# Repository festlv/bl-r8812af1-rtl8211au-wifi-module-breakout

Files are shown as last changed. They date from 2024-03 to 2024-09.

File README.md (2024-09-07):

# BL-R8812AF1 (RTL8211AU) module breakout

Features:
* 5..18V power input
* JST GH for USB/power
* 12pin FFC connector (pinout for IVG-G3S / GK7205V210+IMX307) camera module- USB, microSD slot (optionally: power)

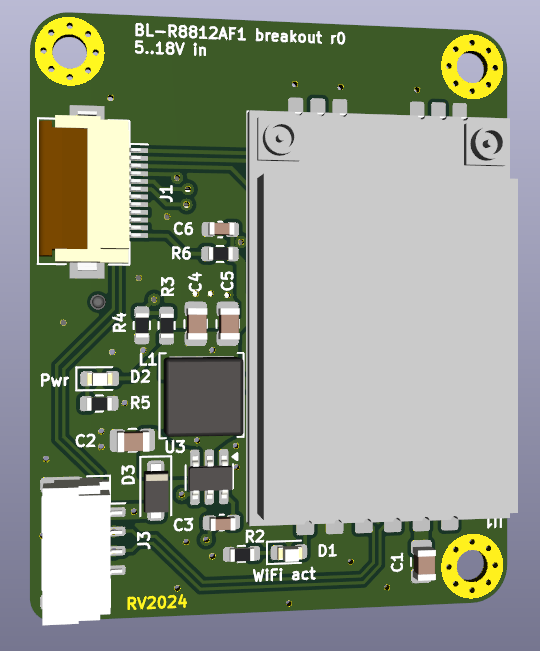
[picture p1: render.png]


Current state:
* Power input tested and working fine at 5 and 12V
* WiFi module works
* FFC connection untested

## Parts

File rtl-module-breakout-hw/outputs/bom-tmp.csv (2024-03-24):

Item | Qty | Reference(s) | Value | LibPart | Footprint | Datasheet | DNP | AltMPN | AltManufacturer | Config | LCSC# | MPN | Manufacturer
1 | 3 | C1, C4, C5 | 22uF | Device:C_Small | Capacitor_SMD:C_0805_2012Metric | ~ |  |  |  |  | C380338
2 | 1 | C2 | 10uF | Device:C_Small | Capacitor_SMD:C_0805_2012Metric | ~ |  |  |  |  | C15850
3 | 2 | C3, C6 | 0.1uF | Device:C_Small | Capacitor_SMD:C_0603_1608Metric | ~
4 | 1 | D1 | LED_GREEN | hadv-ui:LED_GREEN | LED_SMD:LED_0603_1608Metric | ~ |  |  |  |  | C434423 | SZYY0603YG | Yongyu Photoelectric
5 | 1 | D2 | LED_RED | hadv-ui:LED_RED | LED_SMD:LED_0603_1608Metric | ~ |  |  |  |  | C434419 | SZYY0603R | Yongyu Photoelectric
6 | 1 | D3 | DSS34 | hadv-diodes:DSS34 | Diode_SMD:D_SOD-123F | https://datasheet.lcsc.com/lcsc/2004141809_BORN-DSS34_C511866.pdf |  |  |  |  | C511866 | DSS34 | BORN
7 | 1 | J1 | FFC_12p_H | hadv-connectors:FFC_12p_H | Connector_FFC-FPC:Hirose_FH12-12S-0.5SH_1x12-1MP_P0.50mm_Horizontal | ~ |  |  |  |  | C262290 | AFC24-S12FIC-00 | JUSHUO
8 | 1 | J2 | TF-01A | hadv-connectors:TF-01A | hadv-connectors:TF-01A | https://datasheet.lcsc.com/lcsc/1811082127_Korean-Hroparts-Elec-TF-01A_C91145.pdf |  |  |  |  | C91145 | TF-01A | Korean Hroparts
9 | 1 | J3 | JST-GH-4H | hadv-connectors:JST-GH-4H | Connector_JST:JST_GH_SM04B-GHS-TB_1x04-1MP_P1.25mm_Horizontal | ~ |  | X1251WRS-04HF-LPSW | XKB |  | C388709 | SM04B-GHS-TB | JST
10 | 1 | L1 | LQH5BPN3R3N38L | hadv-inductors:LQH5BPN3R3N38L | Inductor_SMD:L_Sunlord_SWPA5020S | ~ |  |  |  |  | C703751 | LQH5BPN3R3N38L | Murata
11 | 2 | R1, R4 | 10K | Device:R_Small | Resistor_SMD:R_0603_1608Metric | ~
12 | 2 | R2, R5 | 220R | Device:R_Small | Resistor_SMD:R_0603_1608Metric | ~ |  |  |  |  | C22962
13 | 1 | R3 | 31K6 | Device:R_Small | Resistor_SMD:R_0603_1608Metric | ~ |  |  |  |  | C25967 | 0603WAF3162T5E
14 | 1 | R6 | 0R | Device:R_Small | Resistor_SMD:R_0603_1608Metric | ~ | DNP |  |  | DNP
15 | 1 | U1 | ~ | hadv-rf:BL-R8812AF1 | hadv-rf:BL-R8812AF1 |  |  |  |  |  |  | BL-R8812AF1 | Unknown
16 | 1 | U3 | AP62300WU | hadv-vregs:AP62300WU | Package_TO_SOT_SMD:TSOT-23-6 | https://www.diodes.com/assets/Datasheets/AP62300_AP62301_AP62300T.pdf |  |  |  |  | C1880390 | AP62300WU-7 | Diodes Inc

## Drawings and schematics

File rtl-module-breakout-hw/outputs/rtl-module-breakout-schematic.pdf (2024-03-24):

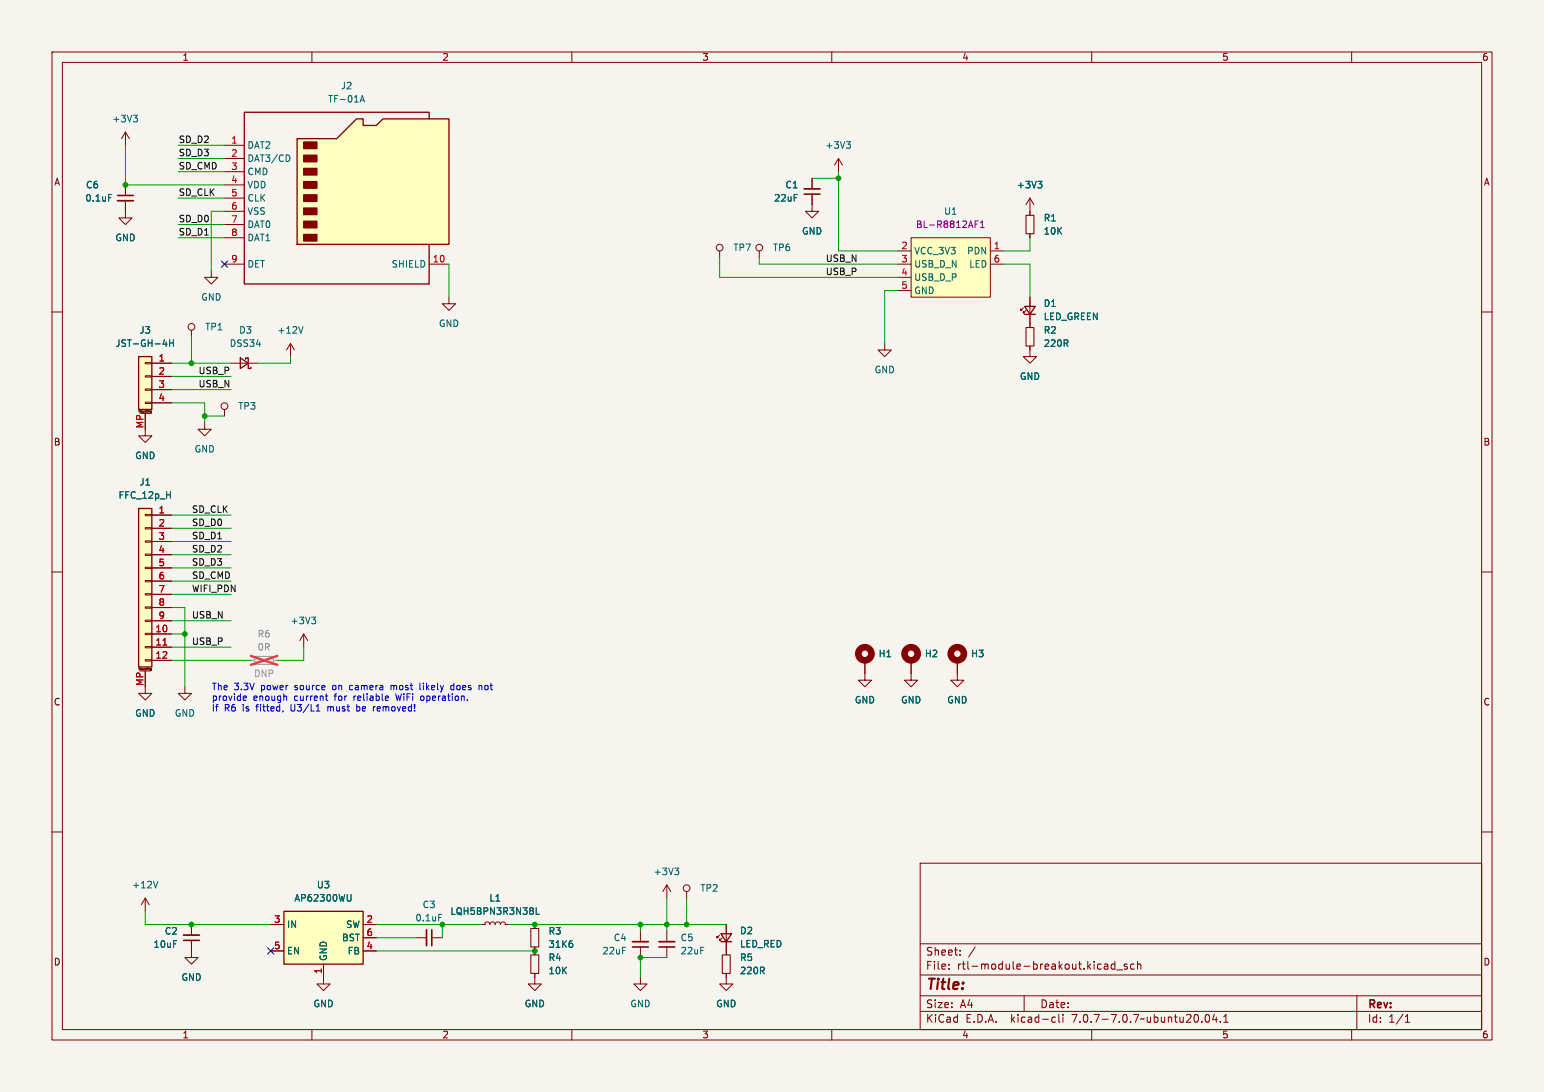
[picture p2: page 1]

Id: 1/1 Title: File: rtl-module-breakout.kicad_sch Sheet: /

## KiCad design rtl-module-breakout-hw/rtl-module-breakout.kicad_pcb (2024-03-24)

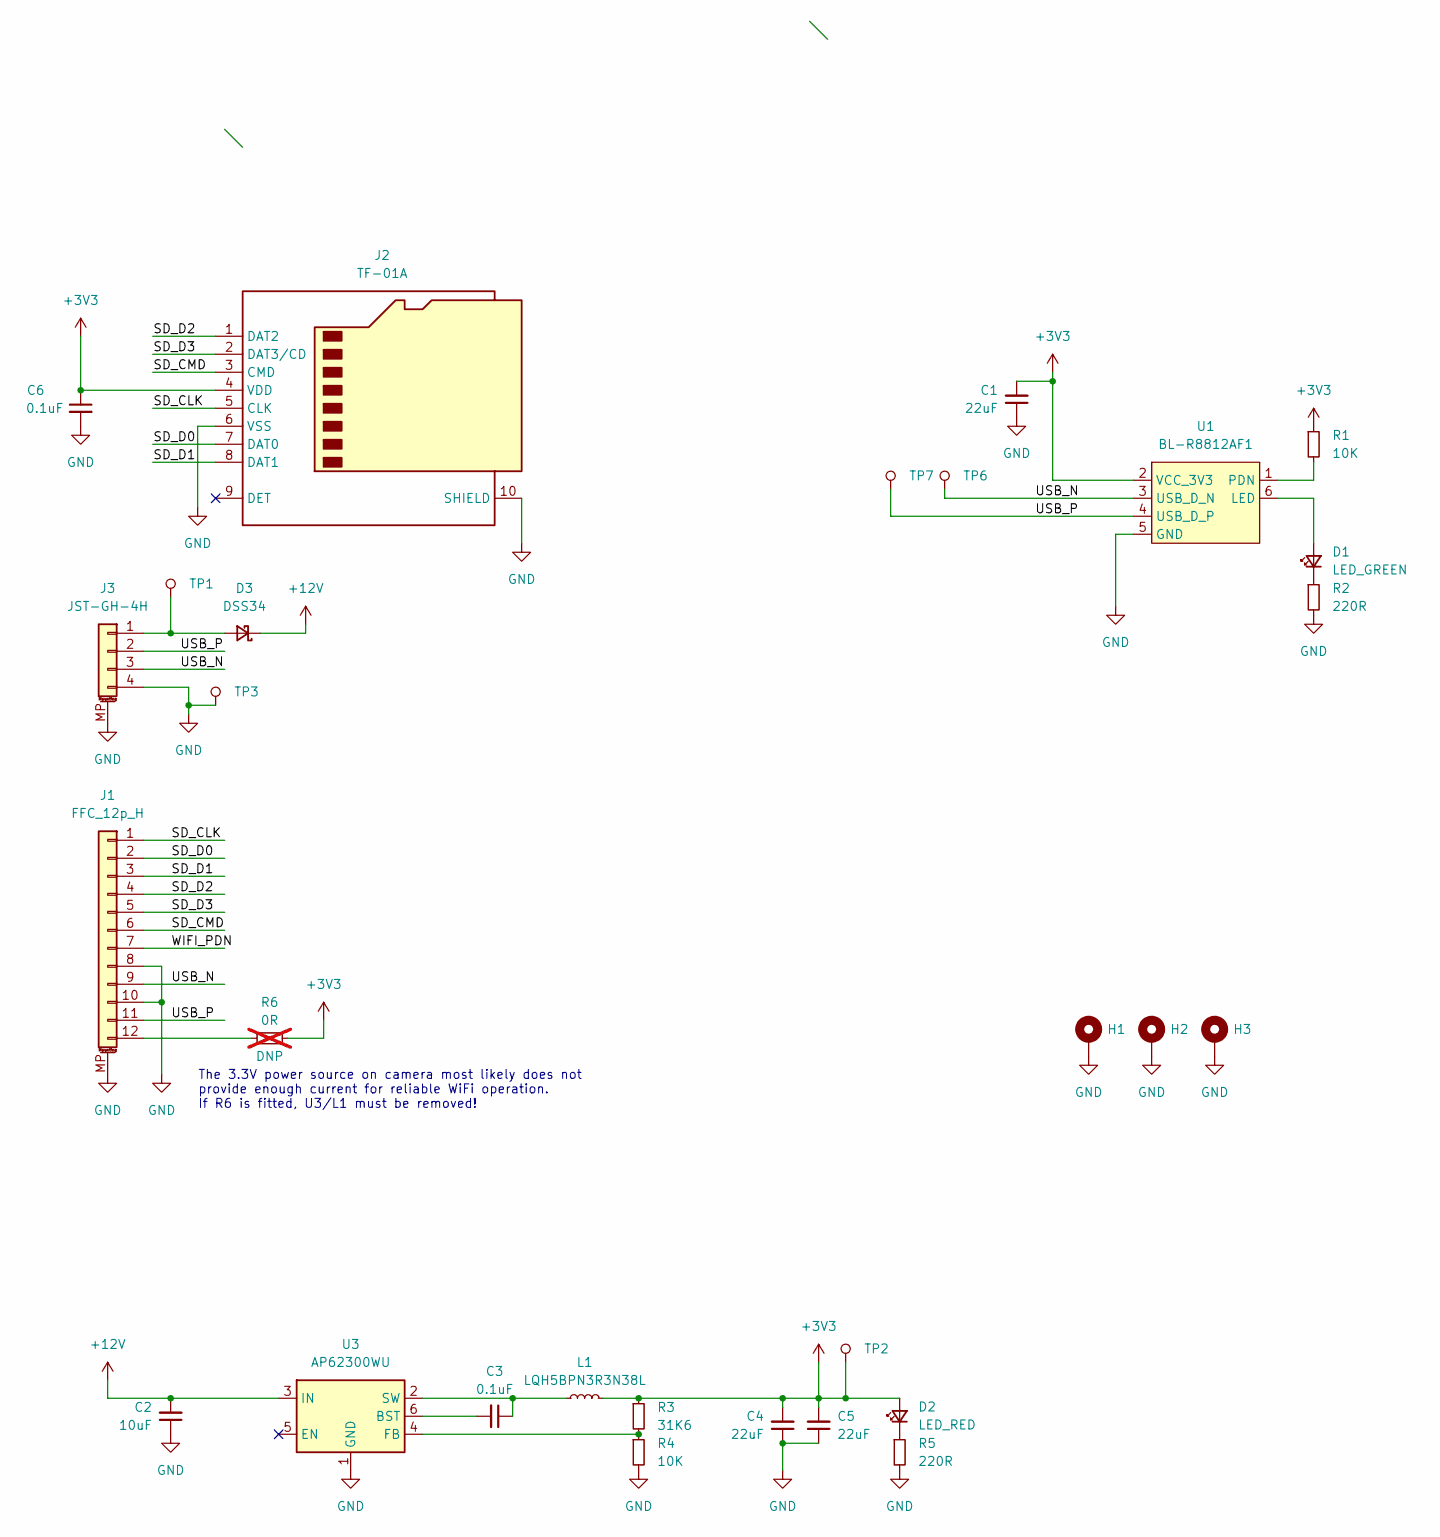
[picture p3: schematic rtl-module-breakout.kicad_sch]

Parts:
C1, C4, C5: 22uF; C_0805_2012Metric; LCSC# C380338
C2: 10uF; C_0805_2012Metric; LCSC# C15850
C3, C6: 0.1uF; C_0603_1608Metric
D1: LED_GREEN; LED_0603_1608Metric; MPN SZYY0603YG; LCSC# C434423
D2: LED_RED; LED_0603_1608Metric; MPN SZYY0603R; LCSC# C434419
D3: DSS34; D_SOD-123F; MPN DSS34; LCSC# C511866
H1, H2, H3: MH_2.2mm; MountingHole_2.2mm_M2_Pad_Via
J1: FFC_12p_H; Hirose_FH12-12S-0.5SH_1x12-1MP_P0.50mm_Horizontal; MPN AFC24-S12FIC-00; LCSC# C262290
J2: TF-01A; MPN TF-01A; LCSC# C91145
J3: JST-GH-4H; JST_GH_SM04B-GHS-TB_1x04-1MP_P1.25mm_Horizontal; MPN SM04B-GHS-TB; LCSC# C388709
L1: LQH5BPN3R3N38L; L_Sunlord_SWPA5020S; MPN LQH5BPN3R3N38L; LCSC# C703751
R1, R4: 10K; R_0603_1608Metric
R2, R5: 220R; R_0603_1608Metric; LCSC# C22962
R3: 31K6; R_0603_1608Metric; MPN 0603WAF3162T5E; LCSC# C25967
R6: 0R; R_0603_1608Metric; not fitted
TP1, TP2, TP3, TP6, TP7: TP_1MM; TestPoint_Pad_D1.0mm
U1: BL-R8812AF1; MPN BL-R8812AF1
U3: AP62300WU; TSOT-23-6; MPN AP62300WU-7; LCSC# C1880390

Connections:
+3V3: C1.2, C4.2, C5.2, C6.1, D2.2 (A), J2.4 (VDD), L1.2, R1.1, R3.1, R6.2, TP2.1, U1.2 (VCC_3V3)
+12V: C2.2, D3.1 (K), U3.3 (IN)
/SD_CLK: J1.1, J2.5 (CLK)
/SD_CMD: J1.6, J2.3 (CMD)
/SD_D0: J1.2, J2.7 (DAT0)
/SD_D1: J1.3, J2.8 (DAT1)
/SD_D2: J1.4, J2.1 (DAT2)
/SD_D3: J1.5, J2.2 (DAT3/CD)
/USB_N: J1.9, J3.3, TP6.1, U1.3 (USB_D_N)
/USB_P: J1.11, J3.2, TP7.1, U1.4 (USB_D_P)
/WIFI_PDN: J1.7
GND: C1.1, C2.1, C4.1, C5.1, C6.2, H1.1, H2.1, H3.1, J1.8, J1.10, J1.MP (MountPin), J2.6 (VSS), J2.10 (SHIELD), J3.4, J3.MP (MountPin), R2.2, R4.2, R5.2, TP3.1, U1.5 (GND), U1.7 (GND), U1.9 (GND), U1.10 (GND), U1.12 (GND), U3.1 (GND)
unnamed: D1.2 (A), U1.6 (LED)
unnamed: D1.1 (K), R2.1
unnamed: D2.1 (K), R5.1
unnamed: D3.2 (A), J3.1, TP1.1
unnamed: J1.12, R6.1
unnamed: R1.2, U1.1 (PDN)
unnamed: C3.2, U3.6 (BST)
unnamed: R3.2, R4.1, U3.4 (FB)
unnamed: C3.1, L1.1, U3.2 (SW)

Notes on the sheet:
The 3.3V power source on camera most likely does not provide enough current for reliable WiFi operation. If R6 is fitted, U3/L1 must be removed!

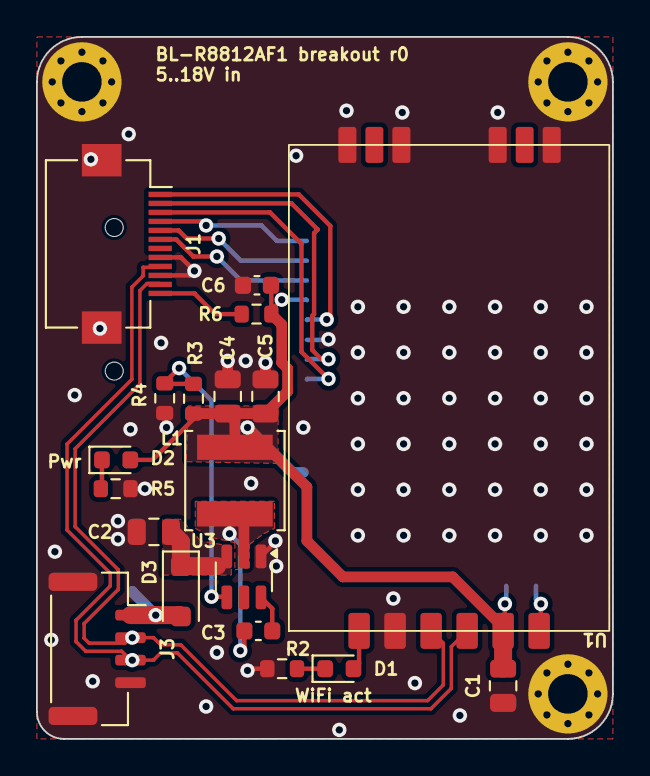
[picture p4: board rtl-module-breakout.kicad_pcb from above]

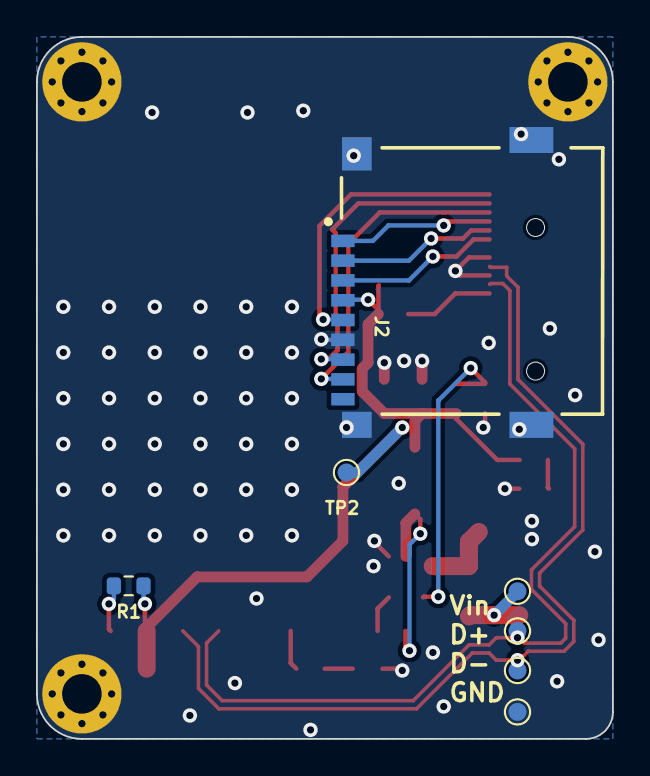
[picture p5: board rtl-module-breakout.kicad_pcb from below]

Board: 2 copper layers, 32.0 x 39.0 mm, 29 parts (7 on the bottom side), 20 nets.

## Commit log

2024-03-24 Initial revision
    [rtl-module-breakout-single-sided.kicad_pcb, rtl-module-breakout.kicad_pcb, rtl-module-breakout.kicad_sch]
2024-03-24 Add outputs
    [bom-tmp.csv, bom.csv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]
